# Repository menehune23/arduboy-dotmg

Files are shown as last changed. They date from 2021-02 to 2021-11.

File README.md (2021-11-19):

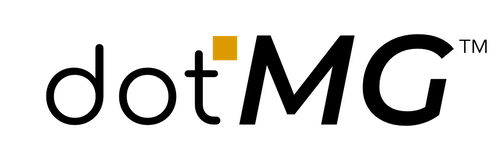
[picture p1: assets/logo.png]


**dotMG** is an

```// Arduboy-compatible```

```// cartridge-based```

```// hackable```

DIY game console!

<p align="center">
   <img src="assets/dotmg.png" width="250px">
   <img src="assets/dotmg_advance.png" width="250px">
</p>
<p align="center">
   <img src="assets/front_black.png" width="150px">
   <img src="assets/advance_front_black.png" width="300px">
</p>

> More pictures in the [assets](assets) folder!

Designed to remind you of the early days of handheld gaming, dotMG combines game cartridges with Arduboy greatness!

## Features

- Swappable game cartridges based on the Arduino Pro Micro (including reverse cart protection)

- Hackability via EXT header (exposes SPI/I2C/GPIO pins) -- add your own crank, accelerometer, joystick, flash chip, RGB LED, or any other add-on of your own creation!

- Rechargeable battery (with play 'n charge capability via load-sharing circuitry)

- Analog volume control

- Large 2.44" 128x64 high-contrast OLED display

## Documentation

Select one of the following to learn how to build and use dotMG

- [Build Guide](docs/build.md)
- [Usage Guide](docs/usage.md)
- [PCB Ordering Guide](docs/pcb-ordering.md)
- [Custom Shell Guide](docs/custom-shell.md)

## Reporting Issues

If you've found a hardware/software bug, have feedback, or if you just need help troubleshooting, please [file an issue](https://github.com/menehune23/arduboy-dotmg/issues). I'm just one person, so I'll try to respond as best as I can (bugs will take priority over feedback and troubleshooting).

## License

Copyright (c) 2021 Andrew Meyer.

[Attribution-NonCommercial-ShareAlike 4.0 International (CC BY-NC-SA 4.0)](https://creativecommons.org/licenses/by-nc-sa/4.0/)

This project is for DIYers and hobbyists. It may not be used for anything considered commercial use without the author's explicit, written consent. Otherwise, use at your own risk and have fun!

**This project is not officially licensed or endorsed by [Arduboy](https://arduboy.com).**

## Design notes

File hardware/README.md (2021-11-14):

# Hardware

This directory contains the hardware design files for dotMG. To use the files here to order PCBs, see the [PCB Ordering Guide](/docs/pcb-ordering.md).

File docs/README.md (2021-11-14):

# Documentation

Select one of the following to learn how to build and use dotMG

- [Build Guide](build.md)
- [Usage Guide](usage.md)
- [PCB Ordering Guide](pcb-ordering.md)
- [Custom Shell Guide](custom-shell.md)

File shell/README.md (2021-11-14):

# Shell

This directory contains the shell design files for dotMG. To use the files here to laser-cut your own shell, see the [Custom Shell Guide](/docs/custom-shell.md).

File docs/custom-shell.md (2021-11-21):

# Custom dotMG Shells

If you'd like to change up the shell from the PCB-based one, this repo contains SVG and EPS files under the [`shell`](/shell) directory for laser-cutting your own. Use these to upload to a laser-cutting service (e.g. [Ponoko](https://ponoko.com)) or cut with your own laser cutter.

Below are some tips to keep in mind when ordering or setting up your equipment.

## Color Layers

Each file is comprised of two color layers:
- **Light gray/purple:** Cutting
- **Dark gray:** Engraving

> For a simpler look (or to save money on laser-cutting services) you can ignore the engraving layer when ordering or setting up your equipment.

## Dimensions

Double check that your part dimensions will come out as follows:
- **dotMG**: 73.9mm (width) x 87.2mm (height)
- **dotMG Advance**: 121.1mm (width) x 55.9mm (height)

## Thickness

The recommended part thickness is 1.5-2.0mm (preferably 1.5mm). This is most important for the front shell, as too much thickness will impact the ability to press the buttons.

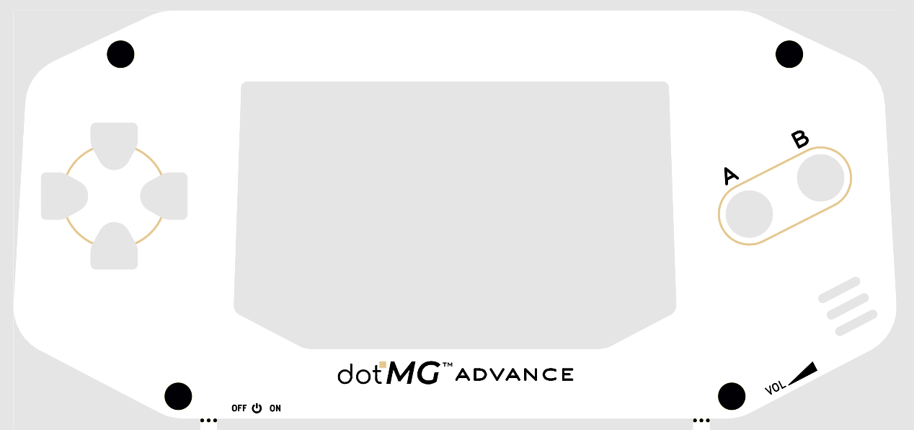
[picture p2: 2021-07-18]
assets/advance_front_white.png

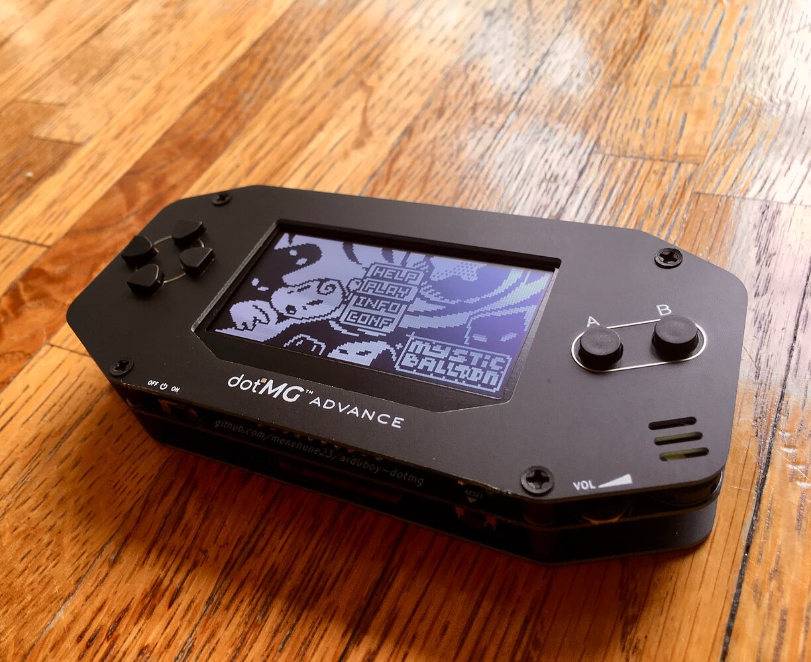
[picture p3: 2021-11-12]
assets/dotmg_advance.png

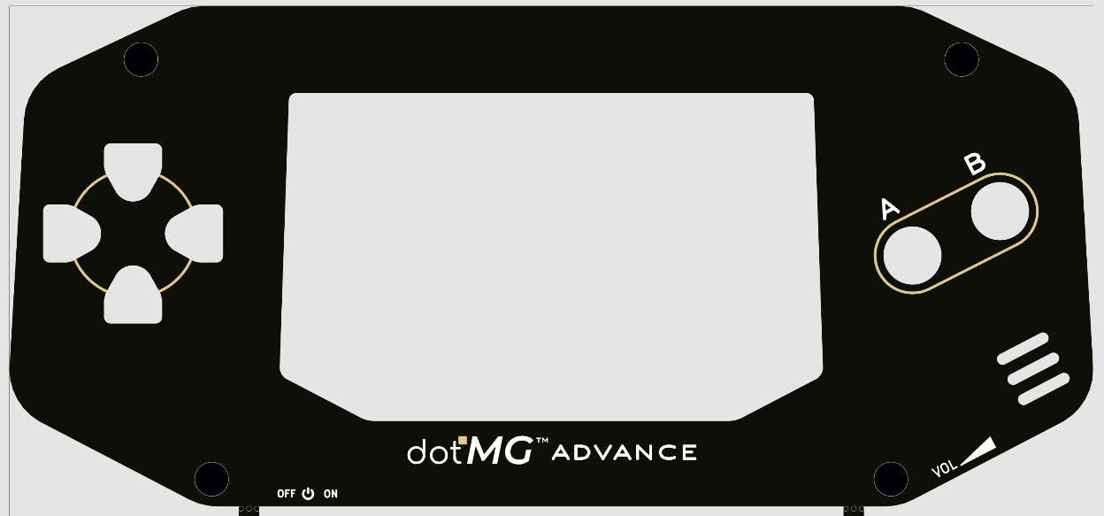
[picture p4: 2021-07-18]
assets/advance_front_black.png

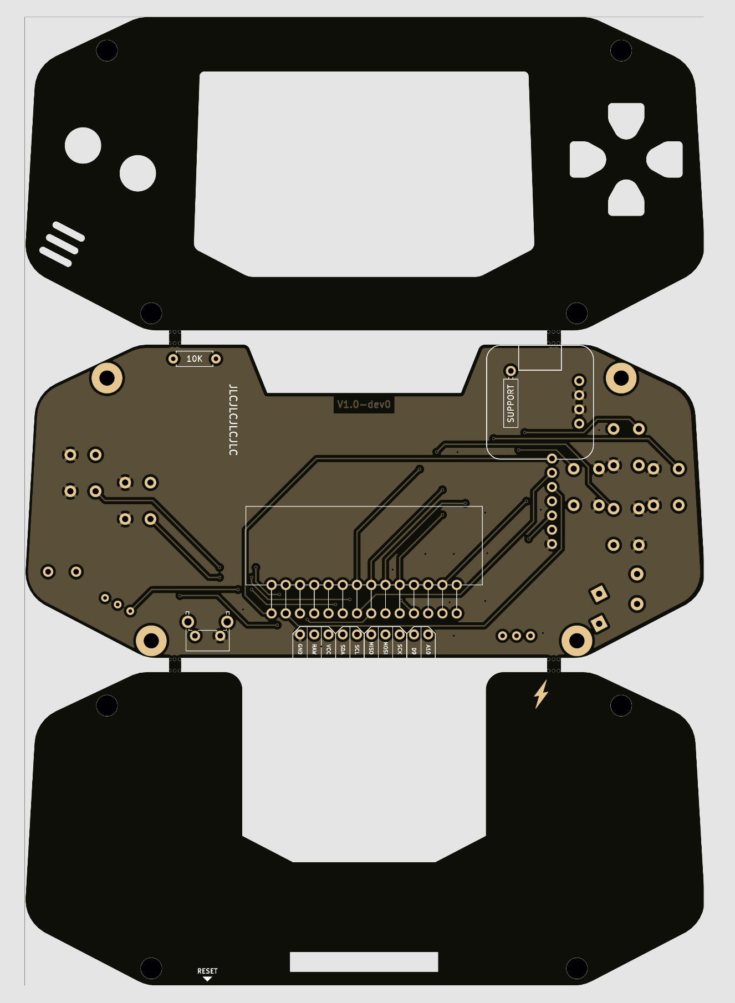
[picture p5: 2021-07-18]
assets/advance_back.png

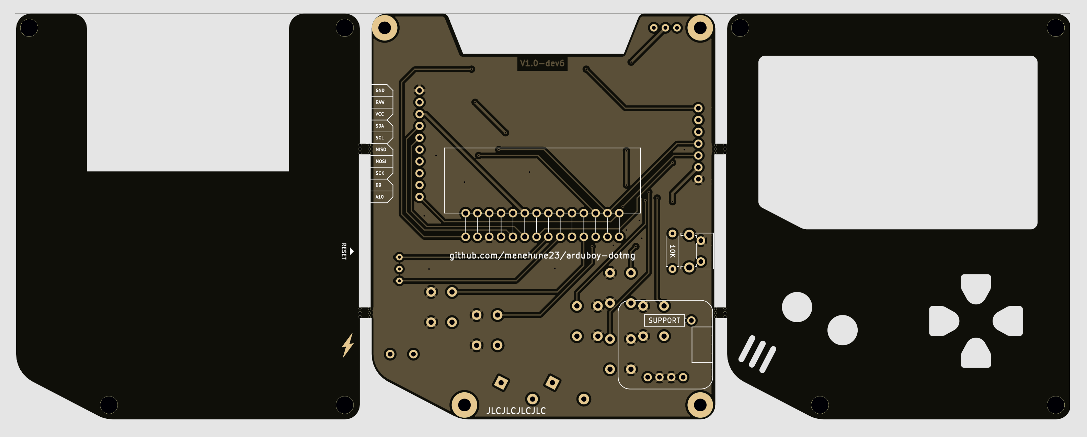
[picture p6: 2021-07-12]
assets/system_back.png

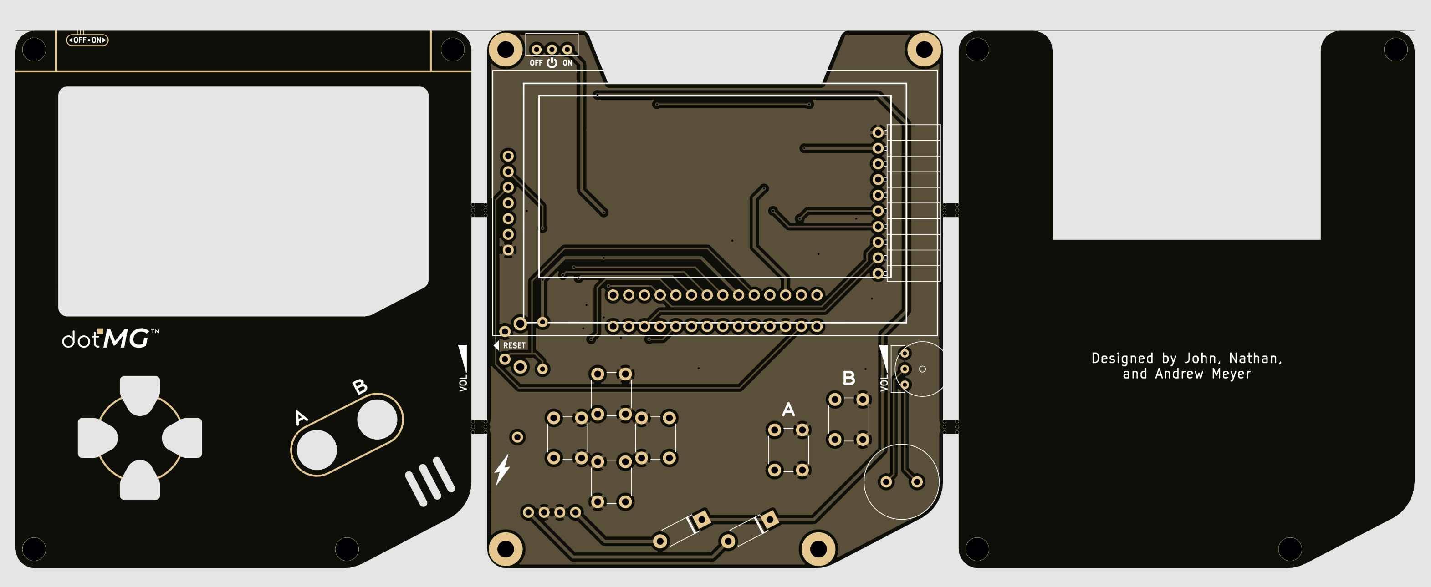
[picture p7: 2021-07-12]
assets/system_front.png

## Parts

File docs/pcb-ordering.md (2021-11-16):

# Ordering dotMG PCBs

The board design files in this repo are optimized for [JLC PCB](jlcpcb.com). Gerber files can be found in this repo under [`hardware`](/hardware) sub-directories. Compress the desired versioned sub-directory to a ZIP file to upload to JLC PCB.

The system PCB comes with three parts, connected by breakaway tabs: the main board and two shell boards (front and back). You can also [laser-cut your own shell](custom-shell.md).

Below are the recommended settings for the JLC PCB order page:

## Cart

- **Base material:** FR-4
- **Layers:** 2
- **Thickness:** 1.0mm (required to fit in connector slot)
- **Finish:** ENIG-RoHS
- **Outer copper weight:** 1oz
- **Gold fingers:** Yes (chamfered if possible, though as of this writing, JLC PCB stopped allowing chamfering on a board this small)
- **Remove order number:** Specify a location (board design contains the required `JLCJLCJLCJLC` text element)

## System

- **Base material:** FR-4
- **Layers:** 2
- **Different design:** 3 (this will also set the delivery format to "panel by customer")
- **Thickness:** 1.2mm
- **Finish:** ENIG-RoHS
- **Outer copper weight:** 1oz
- **Gold fingers:** No
- **Remove order number:** Specify a location (board design contains the required `JLCJLCJLCJLC` text element)

> In a pinch, a lead-free HASL finish can be chosen to save money. For the system, it looks better with ENIG (gold color). For the cart, ENIG is required if gold fingers are selected.

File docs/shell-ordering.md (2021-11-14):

# Ordering dotMG Shells

If you'd like to change up the shell from the PCB-based one, this repo contains SVG files under the [`shell`](/shell) directory for laser-cutting your own. Use these to upload to a laser-cutting service (e.g. [Ponoko](https://ponoko.com)) or cut with your own laser cutter.

Below are some tips to keep in mind when ordering or setting up your equipment:

## SVG Colors

Each SVG is comprised of two colors:
- **Light gray/purple:** Cutting
- **Dark gray:** Engraving

> For a simpler look (or to save money on laser-cutting services) you can ignore the engraving layer when ordering or setting up your equipment.

## Dimensions

Because SVGs don't typically encode units, double check that your part dimensions will come out as follows:
- **dotMG**: 73.9mm (width) x 87.2mm (height)
- **dotMG Advance**: 121.1mm (width) x 55.9mm (height)

> The SVGs in this repo have been tested against [Ponoko](https://ponoko.com), which (as of this writing) reports correct dimensions without needing to scale the SVGs.

## Thickness

The recommended part thickness is 1.5-2.0mm (preferably 1.5mm). This is most important for the front shell, as too much thickness will impact the ability to press the buttons.

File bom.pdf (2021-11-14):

## dotMG (Pro Micro) BOM

Ref | Purpose | Description | Mfr/Vendor | P/N | DigiKey P/N | Qty Unit Price Ext Price Vendor LinkNote
BZ1 | Buzzer | AUDIO PIEZO TRANSDUCER 30V TH | TDK Corporation | PS1240P02CT3 | 445-5229-1-ND | 1 ($ | 0.67) ($ | 0.67) https://www.digikey.com/products/en?keywords=445-5229-1-ND
D1, D2 | Power selection diodes | DIODE SCHOTTKY 20V 1A DO41 | ON Semiconductor | SB120 | SB120FSCT-ND | 2 | $0.43 ($ | 0.86) https://www.digikey.com/products/en?keywords=SB120FSCT-ND
J1 | Game cartridge connector | CART SOCKET 2X14P (28P) | 4UCON | 7861 | | 1 | $4.50 ($ | 4.50) http://www.4uconnector.com/online/SearchPro.asp?FormName=ProSearch&FormAction=search&s_GroupNo=&s_keyword=7861 Possible alternative from AliExpress: https://www.aliexpress.com/item/4001146953252.html
J2 | EXT header | 1X10 RIGHT ANGLE FEMALE HEADER | Adafruit Industries Inc. 1542 | 1 | $0.30 ($ | 0.30) https://www.adafruit.com/product/1542
R1 | Reset button pull-up | RES 10K OHM 1/6W 5% AXIAL | Yageo | CFR-12JB-52-10K | 10KEBK-ND | 1 | $0.10 ($ | 0.10) https://www.digikey.com/products/en?keywords=10KEBK-ND
RV1 | Volume wheel | POT 10K OHM THUMBWHEEL CERM ST | Bourns Inc. | 3352T-1-103LF | 3352T-103LF-ND | 1 ($ | 2.14) ($ | 2.14) https://www.digikey.com/products/en?keywords=3352T-103LF-ND
SW1 | Power switch | SWITCH SLIDE SPDT 300MA 6V | E-Switch | EG1270 | EG1847-ND | 1 | $0.81 ($ | 0.81) https://www.digikey.com/products/en?keywords=EG1847-ND
SW2 | Reset button | SWITCH TACTILE SPST-NO 0.05A 24V - RIGHT ANGLE | TE Connectivity | 1825027-5 | 450-1662-ND | 1 ($ | 0.18) ($ | 0.18) https://www.digikey.com/products/en?keywords=450-1662-ND

SW3, SW4,
SW5, SW6,
SW7, SW8
A/B/up/down/left/right buttons | SWITCH TACTILE SPST-NO 0.05A 24V | Omron Electronics Inc. B3F-1050 | SW404-ND | 6 ($ | 0.32) ($ | 1.92) https://www.digikey.com/products/en?keywords=SW404-ND 1 million cycle lifespan
U1 | Battery charger module | MICRO LIPO USB | Adafruit Industries Inc. 1904 | 1 ($ | 6.95) ($ | 6.95) https://www.adafruit.com/product/1904 Polarity MUST match Adafruit battery, if buying
elsewhere
U2 | Screen | 2.42" OLED DISPLAY | DIY More | 030526LV | 1 ($ 20.99) ($ | 20.99) https://www.diymore.cc/products/2-42-inch-12864-oled-display-module-iic-i2c-spi-serial-for-arduino-c51-stm32-green-white-blue-yellow Should come with 7-pin header
A/B button caps | CAP TACTILE ROUND BLACK | Omron Electronics Inc. B32-2010 | SW1139-ND | 2 ($ | 0.76) ($ | 1.52) https://www.digikey.com/products/en?keywords=SW1139-ND
D-pad button caps | KEY CAP BLACK | Omron Electronics Inc. B32-2110 | Z8523-ND | 4 ($ | 0.92) ($ | 3.68) https://www.digikey.com/products/en?keywords=Z8523-ND
Microcontroller | ARDUINO PRO MICRO 5V 16MHZ | Amazon | 1 ($ | 7.33) ($ | 7.33) https://www.amazon.com/KeeYees-ATmega32U4-Development-Microcontroller-Bootloader/dp/B07FXCTVQP 1 needed per game cart, should come with headers
Rechargeable battery | 500 MAH RECHARGEABLE LIPO | Adafruit Industries Inc. 1578 | 1 ($ | 7.95) ($ | 7.95) https://www.adafruit.com/product/1578 Any 3.7V LiPo will do. Recommended capacity 500mAh or more. Just be sure the wiring polarity matches the battery in this BOM. Longer wire needed for dotMG Advance (about 4.5"). Can be extended by hand or with a JST extender, if needed.
Charger board header | 1X4 STRAIGHT MALE HEADER | Adafruit Industries Inc. 392 | 1 ($ | 0.06) ($ | 0.06) https://www.adafruit.com/product/392
Charger board support | 1X1 RIGHT ANGLE FEMALE HEADER | Adafruit Industries Inc. 1542 | 1 | $0.03 ($ | 0.03) https://www.adafruit.com/product/1542 Mechanical support only. No electrical function.
Battery mounting tape | 1" FOAM MOUNTING SQUARE | Amazon | 1 ($ | 0.12) ($ | 0.12) https://www.amazon.com/Scotch-Mounting-Squares-24-Squares-111-24/dp/B002VLJU52 $2.99 for 24-pack
Front shell standoffs | 7MM M2.5 MALE-FEMALE NYLON STANDOFF | | 4 ($ | 0.10) ($ | 0.40) Good combo option from Adafruit (though screws are NOT countersink): https://www.adafruit.com/product/3299
| | | | | Also easy to find these on AliExpress
Back shell standoffs | 10MM M2.5 FEMALE-FEMALE NYLON STANDOFF | 4 ($ | 0.10) ($ | 0.40)
Shell screws | 6MM (TOTAL LENGTH) M2.5 COUNTERSINK NYLON SCREW | 8 ($ | 0.10) ($ | 0.80)
TOTAL ($ | 61.71)

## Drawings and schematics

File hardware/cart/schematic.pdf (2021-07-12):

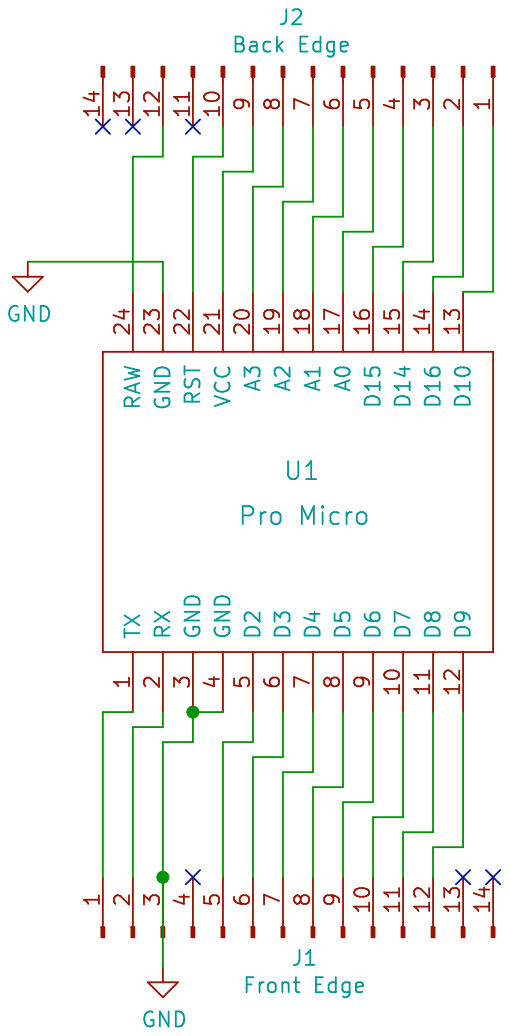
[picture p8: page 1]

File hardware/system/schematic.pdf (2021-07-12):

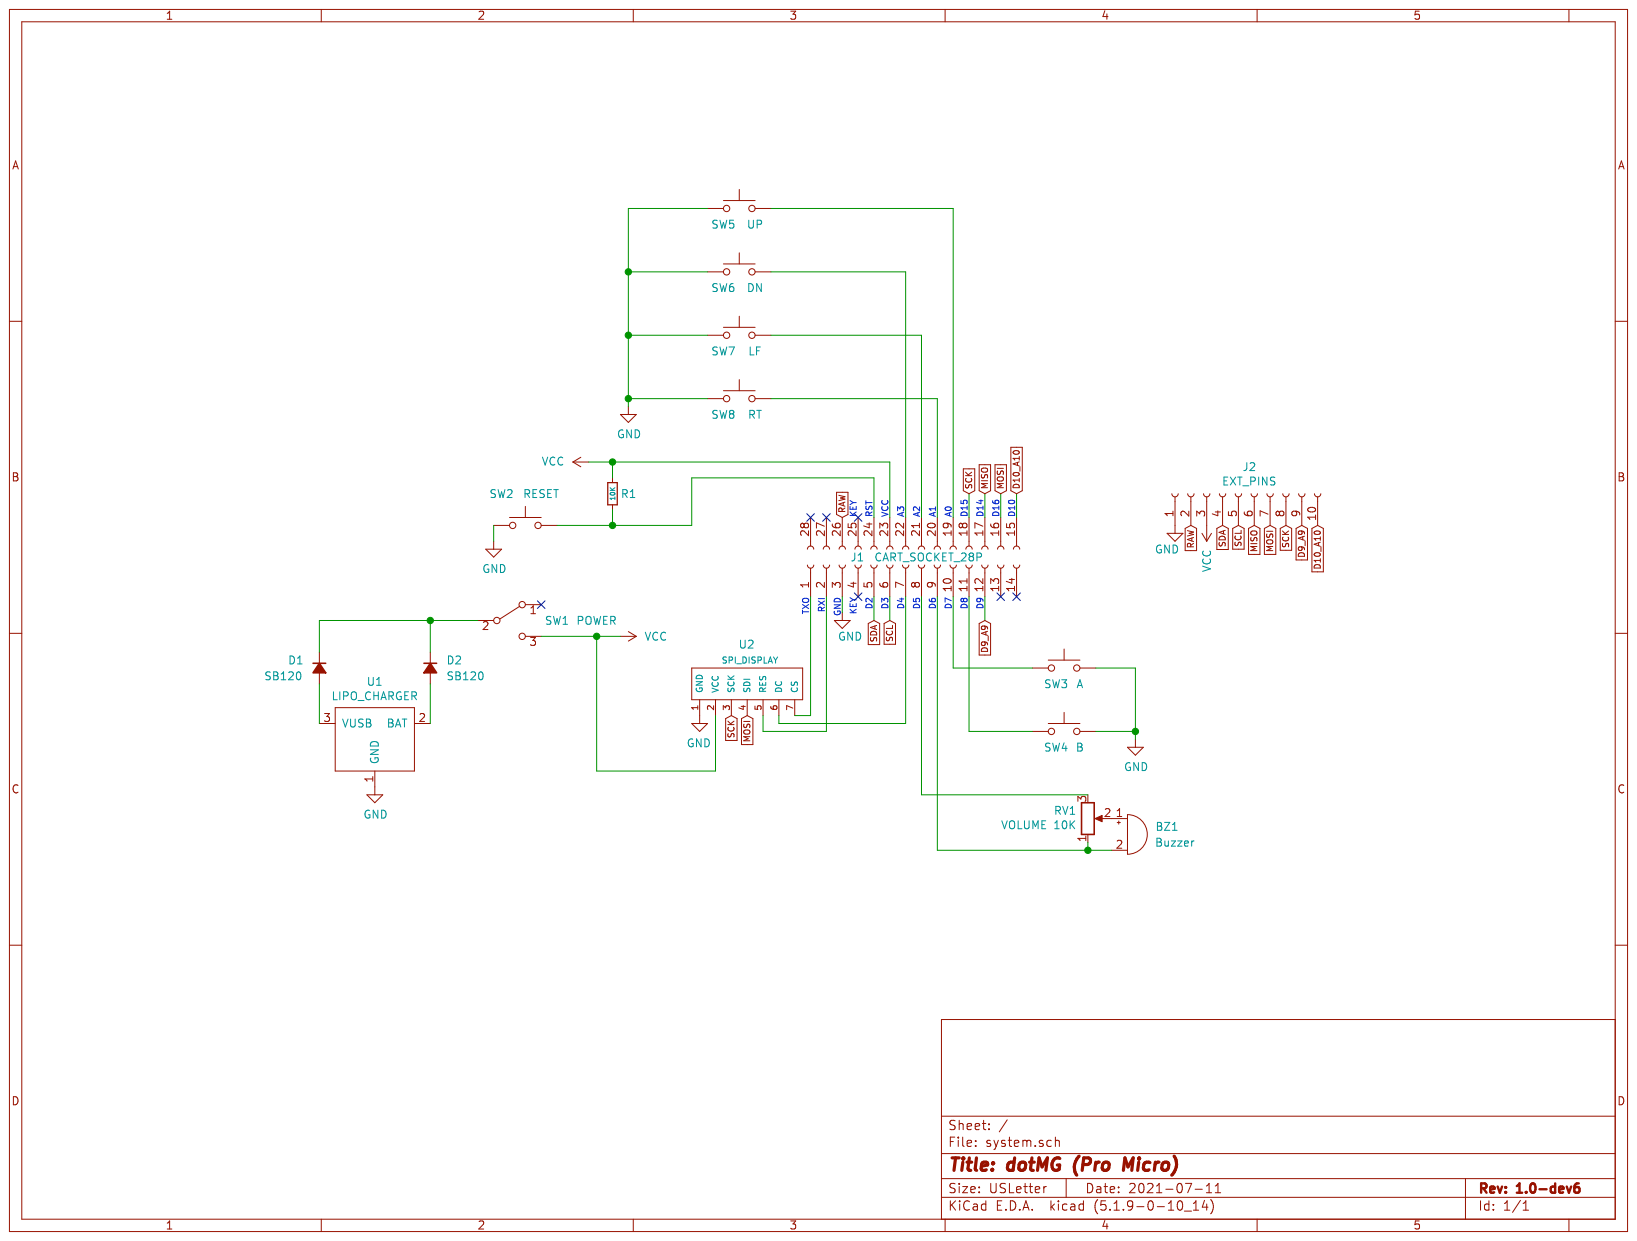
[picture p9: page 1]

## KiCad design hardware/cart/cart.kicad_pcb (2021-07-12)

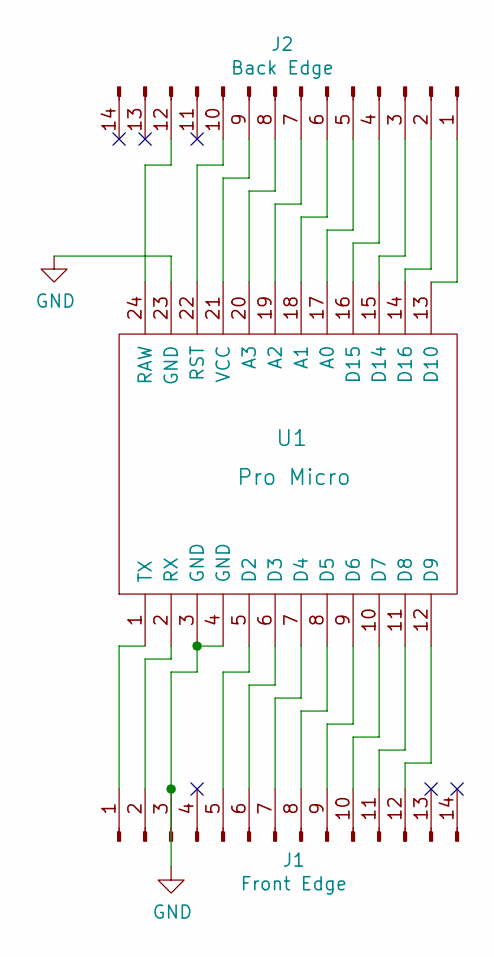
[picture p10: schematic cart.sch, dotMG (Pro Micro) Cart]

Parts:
J1: Front Edge; CARD_CONNECTOR_14_POS
J2: Back Edge; CARD_CONNECTOR_14_POS
U1: Pro Micro; PRO_MICRO

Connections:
GND: J1.3, U1.3 (GND), U1.4 (GND), U1.23 (GND)
unnamed: J1.1, U1.1 (TX)
unnamed: J1.2, U1.2 (RX)
unnamed: J1.5, U1.5 (D2)
unnamed: J1.6, U1.6 (D3)
unnamed: J1.7, U1.7 (D4)
unnamed: J1.8, U1.8 (D5)
unnamed: J1.9, U1.9 (D6)
unnamed: J1.10, U1.10 (D7)
unnamed: J1.11, U1.11 (D8)
unnamed: J1.12, U1.12 (D9)
unnamed: J2.1, U1.13 (D10)
unnamed: J2.2, U1.14 (D16)
unnamed: J2.3, U1.15 (D14)
unnamed: J2.4, U1.16 (D15)
unnamed: J2.5, U1.17 (A0)
unnamed: J2.6, U1.18 (A1)
unnamed: J2.7, U1.19 (A2)
unnamed: J2.8, U1.20 (A3)
unnamed: J2.9, U1.21 (VCC)
unnamed: J2.10, U1.22 (RST)
unnamed: J2.12, U1.24 (RAW)

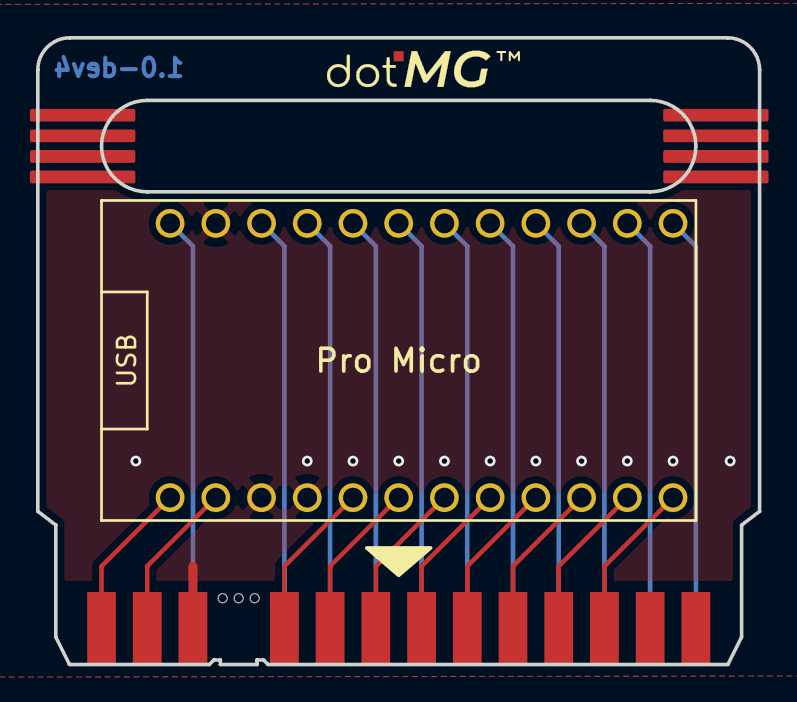
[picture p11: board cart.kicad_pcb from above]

Board: 2 copper layers, 40.1 x 34.8 mm, 3 parts (1 on the bottom side), 22 nets.

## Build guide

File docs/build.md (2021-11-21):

# dotMG Build Guide

Before getting started, be sure you've gathered [parts, materials, and tools](#parts-materials-and-tools). Then follow the steps below:

1. The system board and shell will come as one panel (three boards connected by break-away tabs). After receivig them, separate the shell boards from the main PCB and file down any rough edges (pliers might help break off the tabs too).

1. From there, it's a matter of soldering the components to their marked locations on the boards. Here are a few tips:

    - **For the game cartridge:**

      - The Pro Micro USB port should point to the **left** when the cart is facing you (this should be apparent given the outline on the cart PCB)

      - Trim all leads as flush as possible

      - Break off the small breakaway tab between the 3rd and 4th contacts and stuff it in the system's card connector at the same position (tweezers help here) -- this serves as a mechanical reverse cart protector

    - **For the system**, the recommended soldering order is as follows (trim all leads as flush as possible along the way):

      1. Solder the D-Pad and A/B buttons **first**

      1. Solder the rear components

          > There's a 1-pin right-angle header that sits under the charger board, purely for mechanical alignment (no electrical function) -- be sure to solder it **before** soldering the charger board

          > The reset button should be soldered to the rear side, **not the front**

      1. Solder the front components

          > **IMPORTANT:**
          >
          > - Solder the display **last**
          >
          > - For dotMG Advance, you may need to trim the upper pin on the display before soldering to the system board (so the pin isn't blocked by the charger board)
          >
          > - Diodes are **polarized**! Ensure the band on the diode body lines up with the image on the PCB.

1. Now, plug in the battery and mount it to the lower back of the system board using a small piece of mounting tape
    > **IMPORTANT!** LiPo batteries can be dangerous if mishandled or punctured, as they can catch fire or explode. Use caution and keep this project out of reach of children unless supervised. [Read more about battery safety here](https://learn.adafruit.com/li-ion-and-lipoly-batteries).

    > **Tips:**
    >
    > - Don't use too much mounting tape, or it will be difficult to remove the battery when eventually replacing. A small 0.5"-by-0.5" square will do.
    >
    > - Consider laying down a few strips of PVC tape under where the battery will go, to keep any poorly-trimmed leads from scratching or puncturing the battery
    >
    > - By default, the Adafruit battery charger module is configured to charge at 100mA. You can solder a jumper on it to increase this to 500mA, but **only do this if you know what you're doing**, as it should only be used with batteries of capacity 500mAh or more (and preferably 1000mAh to be safe).
    >
    > - For dotMG Advance, the battery will likely fit best on the left side of the board (when the board is flipped such that the rear side is facing you). This requires the battery wires to be about 4.5" long (as noted in BOM). You can lay the wires along the "canyon" between the card connector and EXT header pins to keep them out of the way during shell assembly.

1. Attach button caps

1. Assemble the shell using the nylon standoffs and screws. Male-female standoffs should go in front and attach to the female-female standoffs on the back side. The shell front and back can then be mounted to the standoffs with the screws.

    > - The shell mounting holes are slightly enlarged to allow for countersink nylon screws to "sink" in a bit
    >
    > - Depending on the screw and standoff lengths, you may need to trim them with a hobby knife to match the lengths in the [BOM](#parts)

## Parts, Materials, and Tools

### Parts

The [BOM can be found here as a PDF](bom.pdf).

See the [PCB Ordering Guide](pcb-ordering.md) if ordering PCBs yourself.

Other helpful links:

- [Full BOM as CSV](bom.csv) (can be uploaded to [Digi-Key](digikey.com) cart)
- [Adafruit Wishlist](http://www.adafruit.com/wishlists/520023), to easily order items available from Adafruit

### Materials & Tools

- Soldering iron and solder

- Phillips-head screwdriver, for assembling shell

- Flush cutters (NOT diagonal cutters), for trimming leads

- Metal file or sandpaper, for trimming board tabs

- Tweezers

- _Optional_: Needle-nose pliers, for trimming board tabs

- _Optional_: Hobby knife (if trimming screws/standoffs)

- _Optional_: PVC (electrical) tape

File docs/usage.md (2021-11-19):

# dotMG Usage Guide

## IDE Setup

If you've already [built your own dotMG](build.md), you can program game cartridges using the Arduino IDE and the custom board package found in this repo. To get going, follow these steps:

1. Add `https://raw.githubusercontent.com/menehune23/arduboy-dotmg/main/board-packages/package_dotmg_index.json` to board manager URLs in the Arduino IDE (found in settings)

1. Open the board manager from the Arduino IDE `Tools` menu, then search for `dotMG` and install

1. Connect the game cartridge to your computer using a micro-USB cable, then select the `dotMG (Pro Micro)` board from the `Tools` menu

    > **Tip:** If you'd like, you may leave the game cartridge plugged into the console when connecting to your computer (likely, you'll need to remove the back shell to make room for the USB cable). If you do this, be sure to connect to the game cartridge's USB port, **not** the charging port on the console. It is OK and expected that the console will turn on in this case, regardless of the power switch position (because power is coming through the cartridge directly).

1. If a USB port was not selected for you in the IDE, select one

## Uploading Games

1. [Select an Arduino sketch to upload](#game-resources) and open it in the Arduino IDE

1. Adjust compilation options via the `Tools` menu, if needed (e.g. to [use an RGB LED](#rgb-led))

1. Click the upload button in the IDE to compile and upload!

> **IMPORTANT!**
>
> The dotMG board package contains its own versions of the Arduboy libraries (among others), which have been updated for compatibility with dotMG. To use dotMG, you must **uninstall [these libraries](/board-package-source/libraries)** from your IDE if you've previously installed them yourself. Otherwise they'll take precedence over the versions in the dotMG board package, leading to confusing compiler errors.
>
> If you had the libraries installed because you were using an official Arduboy, you can still program it without needing to reinstall them. Simply connect your official Arduboy and select the `Arduboy (Official)` board from the `Tools / dotMG` board list before uploading your sketch.

## Game Resources

### Homemade Games

If you want to learn to program your own games for dotMG using the Arduboy libraries, [here's a good place to start](https://community.arduboy.com/t/make-your-own-arduboy-game-part-2-printing-text). Some searches on Google or YouTube for "Arduboy programming tutorial" will also likely yield helpful results.

 The dotMG board package defines the following macros automatically (usable with compiler directives like `#ifdef` or `#ifndef`):

- `DAB_DOTMG_PRO_MICRO`: If defined, signifies that the code will target the `dotMG (Pro Micro)` board (will be undefined if a different board was selected from `Tools`)

- `DAB_DOTMG_PRO_MICRO__NO_RGBLED`: If defined, signifies that `No RGB LED` was selected in the Arduino IDE `Tools` menu (will be undefined if `Has RGB LED` was selected)

### Pre-made Games

If you want to find pre-made games, here are some resources for game sketches:

- [Team ARG Museum](https://team-arg-museum.github.io)
- [Erwin's Arduboy Collection](https://arduboy.ried.cl)

> If you come across `.hex` files, they're likely compiled for the original Arduboy and are not natively compatible with dotMG. For best results, locate the game's source code, then upload using the steps given above.

## Extending dotMG

Ready to hack dotMG and have some real fun? You can use the built-in EXT header to add your own sensors, an [RGB LED](#rgb-led), or even a [flash chip](#flash-chip).

### Pin Initialization

If using the EXT pins for custom input/output in your code, be sure to initialize your pins **after** the Arduboy-specific pins are initialized (usually after `arduboy.begin()` is called). This is needed so that the Arduboy-specific pin initialization doesn't override any of your own initialization (especially true for the RGB LED pins).

### Pinouts

<p align="center">
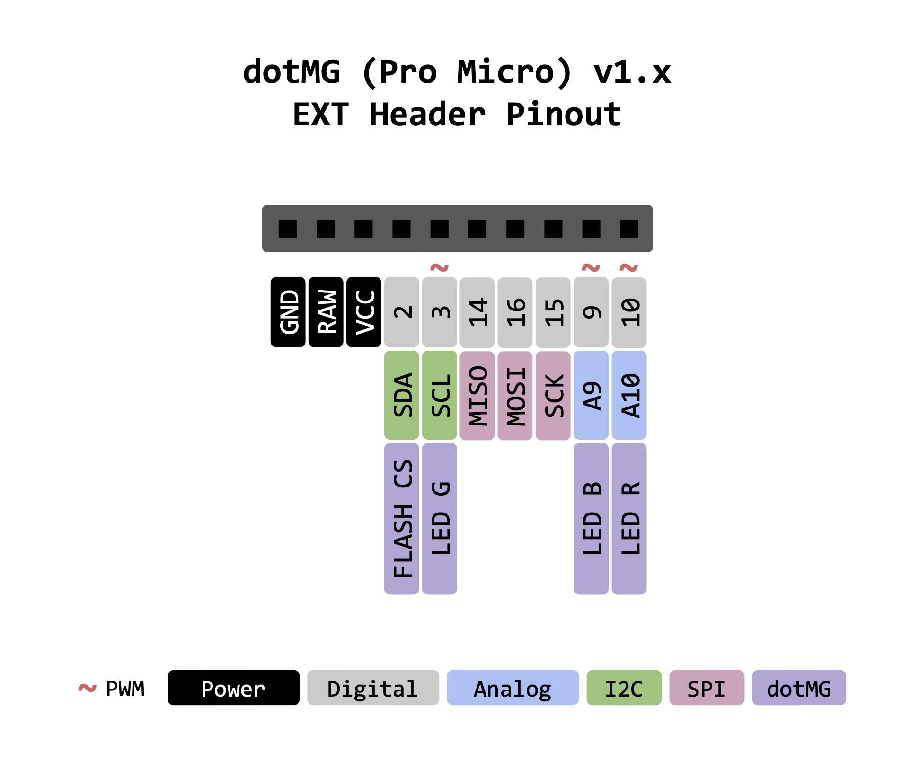
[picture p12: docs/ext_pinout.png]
    
    <br>
    (Click to enlarge)
</p>

<p align="center">
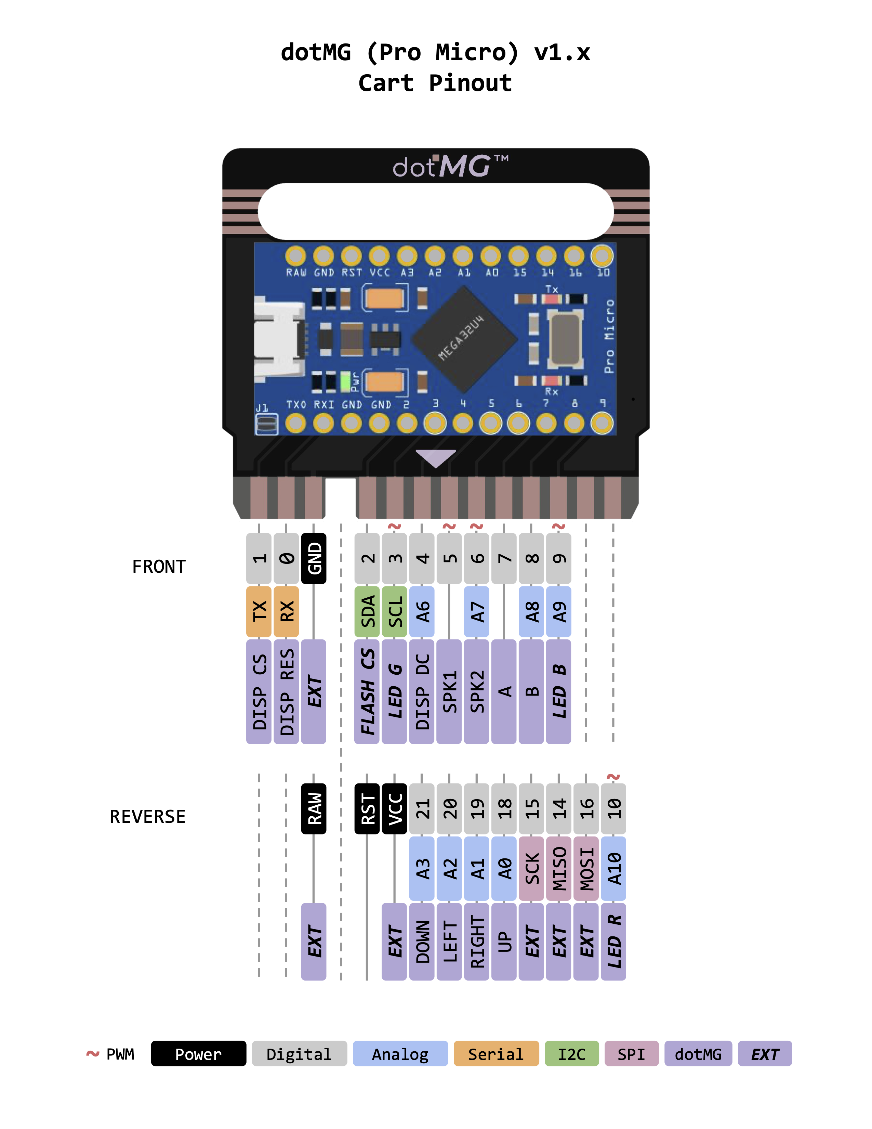
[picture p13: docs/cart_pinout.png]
    
    <br>
    (Click to enlarge)
</p>

### Wiring Diagrams

- [System wiring diagram](/hardware/system/schematic.pdf)
- [Cartrige wiring diagram](/hardware/cart/schematic.pdf)

### RGB LED

Some Arduboy games (or games of your own making) make use of an RGB LED. If you want to add one to your dotMG, be sure to:

- Use a [**common anode** RGB LED](https://www.hackster.io/techmirtz/using-common-cathode-and-common-anode-rgb-led-with-arduino-7f3aa9) (or an equivalent configuration of individual LEDs)
- Use the pins noted in the above pinout
- Don't forget to add resistors!
- Select `Has RGB LED` from the Arduino IDE `Tools` menu before uploading your sketch

Wiring up an RGB LED is optional. If you choose to use those pins for something else instead, simply select `No RGB LED` from the Arduino IDE `Tools` menu. This will remove the LED-lighting code in the Arduboy library so that it doesn't attempt to use those pins during gameplay (see note on [pin initialization](#pin-initialization)).

> If you're not using the Arduboy library, you can still [check the RGB LED menu setting in code](#macros).

### Flash Chip

Flash chips can store hundreds of games at once. Adding a flash chip to dotMG is an advanced topic and is not fully documented here (but [here's a good start](https://community.arduboy.com/t/flash-cart-ridge)). In general, it involves:

- Wiring a flash chip using the above pinout
- Installing the Cathy3K bootloader onto your game cartridge
- Compiling games to `.hex` files and uploading them to the flash chip

If you choose not to use a flash chip, you can use the flash chip select pin (`FLASH CS` in the pinout) for something else, as the pin is only used by the Cathy3K bootloader and the `ArduboyFX` library.

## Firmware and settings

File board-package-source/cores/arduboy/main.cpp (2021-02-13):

/*
  main.cpp - Main loop for Arduino sketches
  Copyright (c) 2005-2013 Arduino Team.  All right reserved.

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
  You should have received a copy of the GNU Lesser General Public
  License along with this library; if not, write to the Free Software
  Foundation, Inc., 51 Franklin St, Fifth Floor, Boston, MA  02110-1301  USA
*/

#include <Arduino.h>

// Declared weak in Arduino.h to allow user redefinitions.
int atexit(void (* /*func*/ )()) { return 0; }

// Weak empty variant initialization function.
// May be redefined by variant files.
void initVariant() __attribute__((weak));
void initVariant() { }

void setupUSB() __attribute__((weak));
void setupUSB() { }

int __attribute__ ((OS_main)) main(void) 
{
	init();

	initVariant();

#if defined(USBCON)
	USBDevice.attach();
#endif
	
	setup();
    
	for (;;) {
		loop();
		if (serialEventRun) serialEventRun();
	}
        
	return 0;
}

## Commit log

2021-01-19 Cart schematic
    [cart.kicad_pcb, cart.sch]
2021-01-19 Add initial cart layout
    [cart-B_Cu.gbr, cart-B_Mask.gbr, cart-B_Paste.gbr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]
2021-01-19 Correct gerber name
    [cart-B_Cu.gbr, cart-B_Mask.gbr, cart-B_Paste.gbr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]
2021-01-21 Add breakaway key pin filler
    [cart-B_Cu.gbr, cart-B_Mask.gbr, cart-B_Paste.gbr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]
2021-01-31 Initial system schematic
    [system.kicad_pcb, system.sch]
2021-02-05 Initial board layout (needs routing)
    [system.kicad_pcb, system.sch]
2021-02-09 Route system board
    [system.kicad_pcb]
2021-02-10 OLED RES -> RST (board), break out RX/D0
    [system.kicad_pcb]
2021-02-11 System front/back, extend cart height
    [cart-B_Cu.gbr, cart-B_Mask.gbr, cart-B_SilkS.gbr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]
2021-02-11 Update main board button labels
    [system-B_Cu.gbr, system-B_Fab.gbr, system-B_Mask.gbr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]
2021-02-11 Add JLC order number lables
    [cart-B_Cu.gbr, cart-B_Mask.gbr, cart-B_Paste.gbr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]
2021-02-11 Fix a via position
    [system-B_Cu.gbr, system-B_Fab.gbr, system-B_Mask.gbr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]
2021-02-12 Bump system to 1.0-dev1
    - Mirror charge symbol on back shell
    - Remove button 3D models
    [system-B_Cu.gbr, system-B_Fab.gbr, system-B_Mask.gbr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]
2021-02-12 Rewire screen regulator Vin to RAW
    - Also add schematic PDFs
    [cart.kicad_pcb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]
2021-02-12 Connect power to VCC instead of RAW
    [system-B_Cu.gbr, system-B_Fab.gbr, system-B_Mask.gbr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]
2021-02-13 Connect display RES to D0/RX
    [system-B_Cu.gbr, system-B_Fab.gbr, system-B_Mask.gbr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]
2021-02-13 Add board package source
2021-02-13 Add board index JSON and updater script
2021-02-14 Update system PCB, fix speaker cutout
    [system-B_Cu.gbr, system-B_Fab.gbr, system-B_Mask.gbr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]
2021-02-14 Update EXT footprint
    [system-B_Cu.gbr, system-B_Fab.gbr, system-B_Mask.gbr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]
2021-02-18 Add usage and build info to readme
    [bom.csv]
2021-03-05 Add grip slot to cart
    - Extends cart by 0.24 in
    - Update to 1.0-dev1
    [cart-B_Cu.gbr, cart-B_Mask.gbr, cart-B_Paste.gbr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]
2021-03-05 Update system board (start of 1.0dev4)
    - Cover cart connector more
    - Move EXT labels closer to edge
    - Add cart grip cutout
    [system.kicad_pcb, system.sch]
2021-03-08 Finish 1.0-dev4 updates
    - Add stylistic display cutout
    - Add support under charger board
    [system-B_Cu.gbr, system-B_Fab.gbr, system-B_Mask.gbr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]
2021-03-08 Increase cart grip top thickness to ~3.5mm
    [cart-B_Cu.gbr, cart-B_Mask.gbr, cart-B_Paste.gbr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]
2021-03-08 Update readme and BOM
    [bom.csv]
2021-03-08 Update soldering notes
2021-03-08 Update cart breakaway tab to use drills (1.0-dev2)
    [cart-B_Cu.gbr, cart-B_Mask.gbr, cart-B_Paste.gbr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]
2021-04-13 Update system and cart
    - Shorten cart by 1mm to account for other connector brand
    - Use 1-pin header for charger board support
    - Fix diode footprint
    - Bump cart/system versions (no gerbers yet)
    [cart.kicad_pcb, cart.sch, system.kicad_pcb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]
2021-04-13 Update BOM
    [bom.csv]
2021-04-13 Add gerbers and updated schematics
    [cart-B_Cu.gbr, cart-B_Mask.gbr, cart-B_Paste.gbr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]
2021-06-08 Remove 3.3V regulator
    [bom.csv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]
2021-07-12 Rename to dotMG
    [cart-B_Cu.gbr, cart-B_Mask.gbr, cart-B_Paste.gbr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]
2021-07-12 Finalize support for no RGB LED
2021-07-12 Set RGB LED pins to low inputs when not in use
2021-07-12 Move power/reset buttons inward slightly
    [system-B_Cu.gbr, system-B_Fab.gbr, system-B_Mask.gbr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]
2021-07-18 Add GBA style system
    [system_advance-B_Cu.gbr, system_advance-B_Fab.gbr, system_advance-B_Mask.gbr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]
2021-07-27 Flip EXT pin labels (advance)
    [system_advance-B_Cu.gbr, system_advance-B_Fab.gbr, system_advance-B_Mask.gbr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]
2021-11-12 Update BOM and README
    [bom.csv]
2021-11-14 Update docs
    - Add shell ordering guide
    - Update links
    - Update BOM
    [bom.csv]
2021-11-15 Update board package
    Changes "RGB LEDs" to "RGB LED"
2021-11-15 Update board package
    Changes "RGB LEDs" to "RGB LED" in menu
2021-11-16 Add official Arduboy board
2021-11-16 Update board list in package index
2021-11-16 Update usage guide: pin initialization
2021-11-16 Fix support for SPI add-ons
    No longer hogs SPI bus for display. Instead, keeps the display CS raised, and asserts only when needed.
2021-11-21 Minor board updates
    - Add logo to main board
    - Increase breakaway tab width (better for fabs)
    [system-B_Cu.gbr, system-B_Fab.gbr, system-B_Mask.gbr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]
